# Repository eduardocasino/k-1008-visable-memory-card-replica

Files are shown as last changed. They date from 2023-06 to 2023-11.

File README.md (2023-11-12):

# K-1008 Visable Memory card replica

## Introduction

Welcome to my K-1008 Visable Memory card replica repository. The card is now completed and successfully tested!

## About

This is a faithful replica of the K-1008 Visable Memory card, a memory expansion and display board for the KIM-1 designed by MTU in the late 70's

I'm using the original K-1008 documentation from various sources on the net, as well as hi-res photos form [Hans Otten's Retro Computing website](http://retro.hansotten.nl/6502-sbc/kim-1-manuals-and-software/kim-1-related-hardware/mtu-k-1012-k-1008/).

As some traces on the top layer are hidden under the components, I've had to add a bit of "frog DNA" to complete the board. I hope it does not differ too much from the original, but it is not visible when the board is populated and it is also electrically correct.

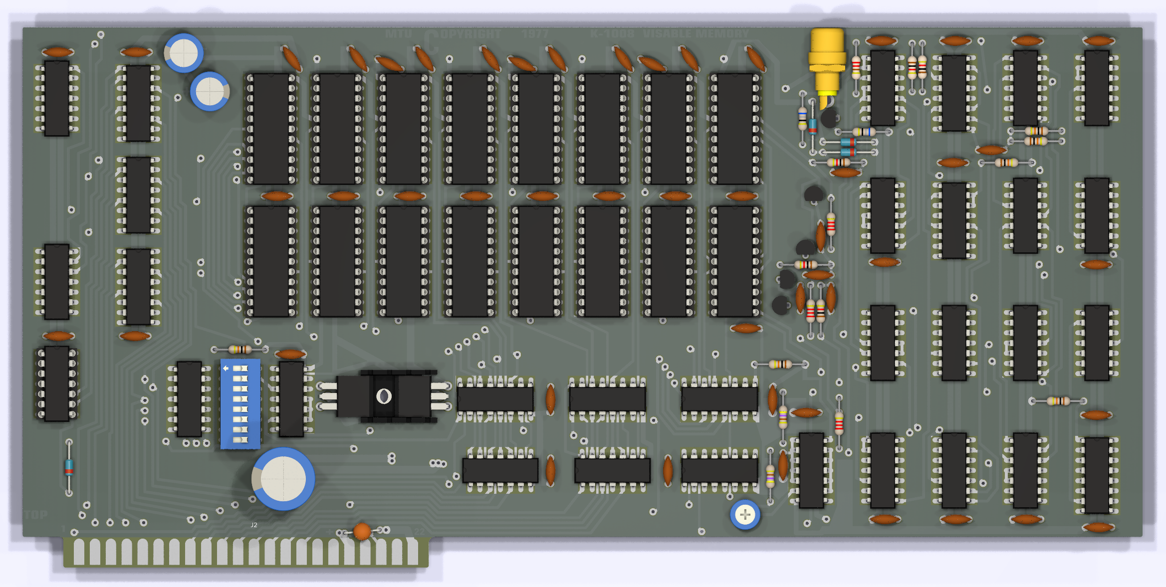
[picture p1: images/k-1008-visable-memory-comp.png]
components

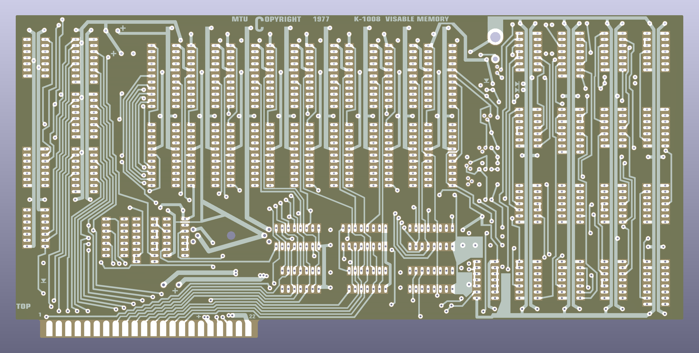
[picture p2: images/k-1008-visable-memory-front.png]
front

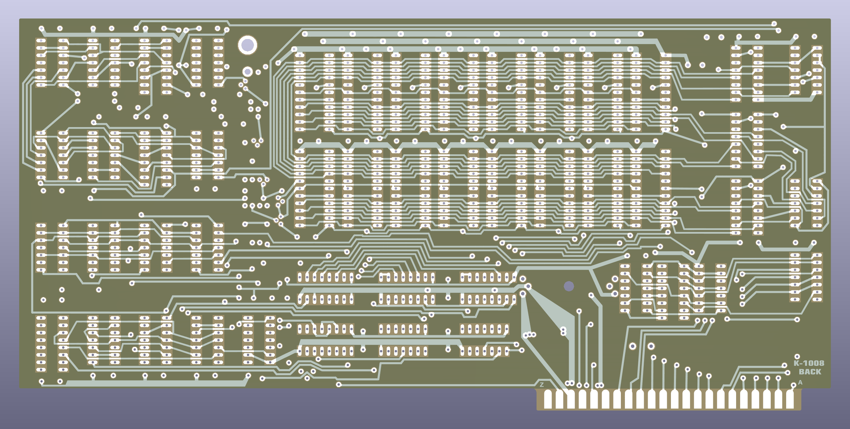
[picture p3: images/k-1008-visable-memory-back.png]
back


The card has been built and tested. All the memory is accessible and passes the memory tests by ["The Glitch Works"](https://github.com/glitchwrks/kim1_memtest) without any error. The image is clear and steady.

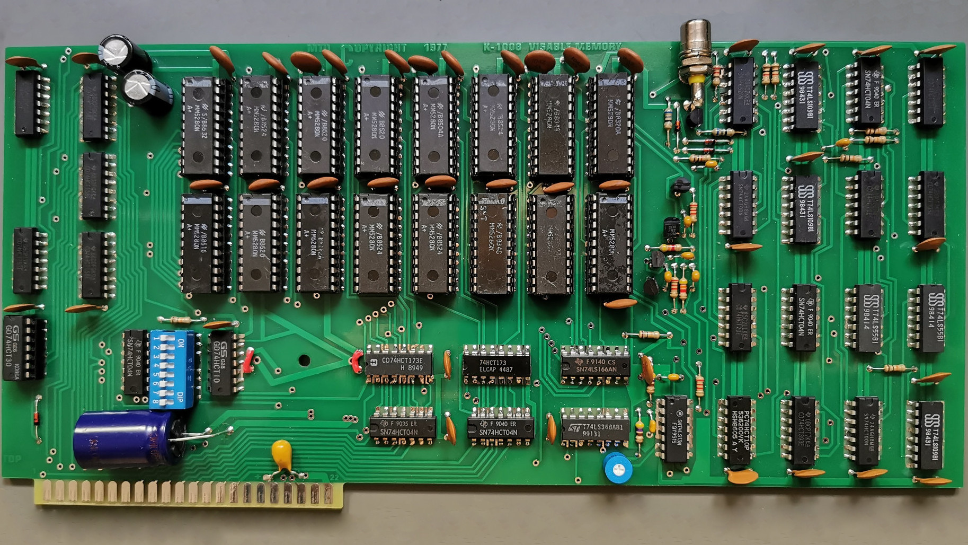
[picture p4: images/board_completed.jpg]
finished board

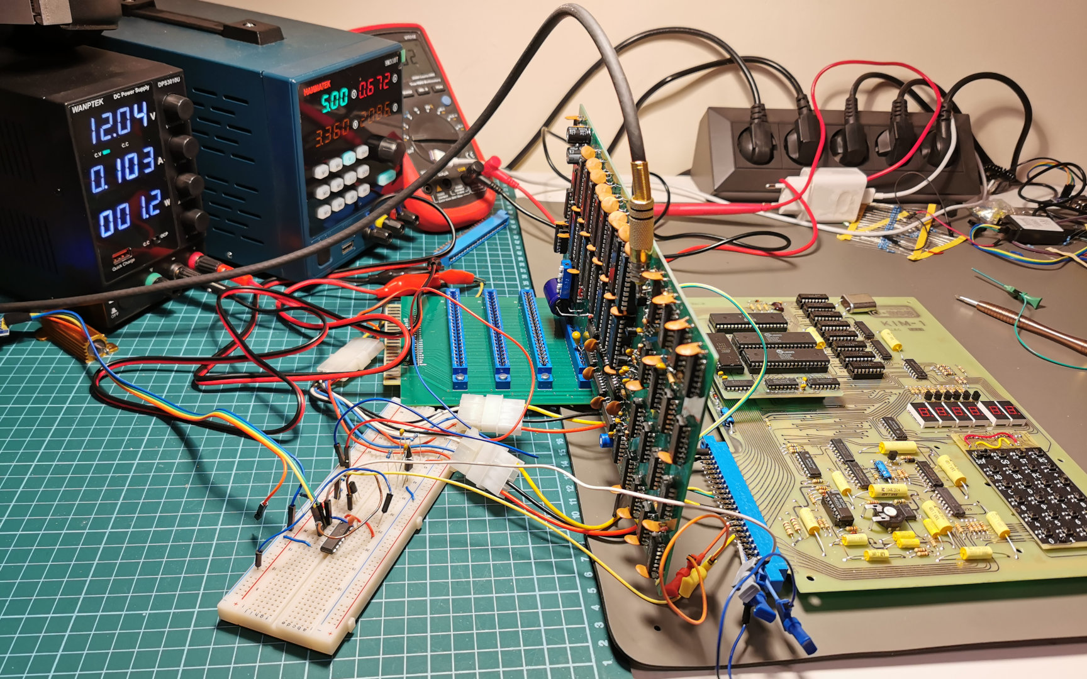
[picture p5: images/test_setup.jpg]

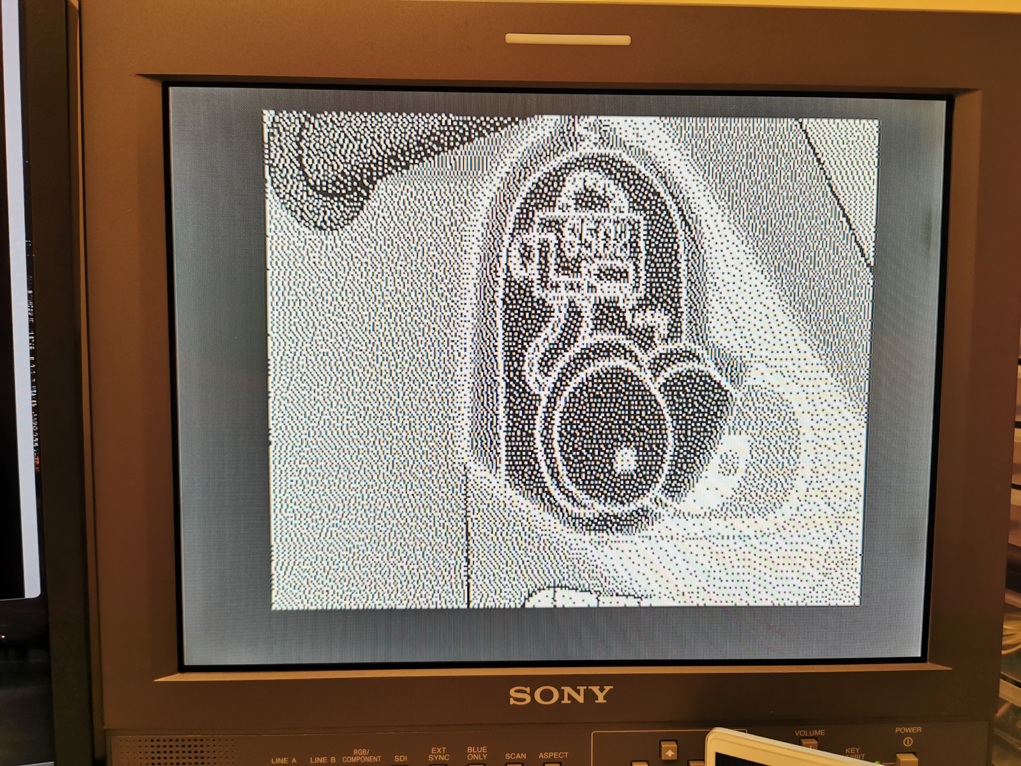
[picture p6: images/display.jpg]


## Building

There is nothing special about building the board. As with any other PCB, start soldering by component height. I'm providing an interactive BOM to assist with the process, but please take in mind:

* There are no modern substitutes for the MM5280 memory chips, but it is still possible to find them as they were widely used for arcade machines. Even the slower MM5280-5 variant should work as they are within the 300ns access/470ns cycle specs for the board (they are 270/470 vs 200/400 for the faster version)
* All the logic ICs are still manufactured, except for the 74LS13 and, I think, the 74LS55, but they are still in stock in some places.
* I've left the regulators unpopulated (bridged) and I use regulated 5V and 12V (an option which the manual suggests), but the LM340T5 is still in production and the LM342P12 can be replaced by the LM340T12.
* the 2N3646/2N9416 used in the level shifters are obsolete and expensive if you find them. I'm using a PN2369A/2N4403 pair, see the schematic for the changes in the base resistors and speed-up capacitors.
* You can use a 1K trimmer instead of the 512R one. The one in the original board is [this one](https://www.bourns.com/docs/Product-Datasheets/3339.pdf), which is a bit expensive for a pot, but you can use any other with the same pin arrangement.
* The 74LS30 (U1) was socketed in the original for easy removal in case of multi-card configuration. All the memories are also socketed. The switch bank (S1) was a normal DIP socket in the original, just add an 8-way DIP switch on top. 
* And, finally, a low Vf Schottky, like the BAT86, is a perfect replacement for the Ge 1N270 diode to simulate an open-collector gate for the VECTOR_FETCH (K7) signal.

The [BOM spreadsheet](https://github.com/eduardocasino/k-1008-visable-memory-card-replica/blob/main/docs/bom.xlsx) is updated with all these changes.

To connect the board to your KIM-1, build a connector as instructed in the [K-1008 User Manual](http://retro.hansotten.nl/uploads/files/K-1008%20Visible%20Memory%20Manual.pdf), or you can use [my adapter board](https://github.com/eduardocasino/kim-1-mtu-expansion-card)

### First setup

Make sure that the microswitches are in a valid position. For example, turn on switches 1, 3 and 6 and leave the rest off to map the video memory at $2000. Refer to the [user manual](http://retro.hansotten.nl/uploads/files/K-1008%20Visible%20Memory%20Manual.pdf) for valid configurations.

Pins 19 (VECTOR_FETCH) and 20 (DECODE_ENABLE) pins of the board connector must be connected to pins J and K of the KIM-1 Application Connector, respectively. If using my expansion board, there are a copule of pin headers for this purpose.

Use a multimeter and adjust the potentiometer until the voltage at pin 13 of U8 is 1.4V. Now you should be able yo read/write from memory addresses from $2000 to $3FFF and a clean image with a random pattern should be shown on the monitor.

### Using the K-1008 with other memory expansion boards

The K-1008 forces low the K7 line when addressing the upper 256 bytes of memory ($FF00-$FFFF), to point to the interrupt vectors that are in the 6530's ROM.

If this is not what you want or the other expansion board has finer control of vector addressing, such as Corsham's, leave U1 (74LS30) unpopulated.

## Licensing

This is a personal project that I am sharing in case it is of interest to any retrocomputing enthusiast and all the information in this repository is provided "as is", without warranty of any kind. I am not liable for any damages that may occur, whether it be to individuals, objects, KIM-1 computers, kittens or any other pets. **It should also be noted that everything in this repository is a work in progress and, although the board has been tested, may contain errors. Therefore, anyone who chooses to use it does so at their own risk**.



This work is licensed under a [Creative Commons Attribution-NonCommercial 4.0 International License](http://creativecommons.org/licenses/by-nc/4.0/).

See the LICENSE.md file for details.

## Acknowledgements

* Hans Otten and his [Retro Computing blog](http://retro.hansotten.nl/). A lot of information and high resolution pictures of a K-1008
* Dave Plummer of [Dave's Garage fame](https://www.youtube.com/c/DavesGarage). Nice hi-res photos and actual board dimensions.
* Budi Prakosa "badgeek" for the [svg2shenzhen](https://github.com/badgeek/svg2shenzhen) plugin for Inkscape
* qu1ck for his [interactive HTML BOM plugin](https://github.com/openscopeproject/InteractiveHtmlBom)

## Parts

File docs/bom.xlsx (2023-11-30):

Quantity | Ref | Value | Notes
1 | U1 | 74LS30
1 | - | DIP-14 socket
5 | U2, U4, U6, U16, U46 | 74LS04
2 | U3, U11 | 74LS10
2 | U5, U7 | 74LS173
1 | U8 | 74LS368
1 | U9 | 74LS166
1 | U10 | 74LS13 | Discontinued, but still available from some dealers
3 | U12, U19, U32 | 74LS393
2 | U13, U29 | 74LS00
3 | U14, U30, U45 | 74LS109
2 | U15, U47 | 74LS20
2 | U17, U18 | 74LS55 | Discontinued, but still available from some dealers
3 | U20, U33, U35 | 74LS158
16 | U21-U28, U36-U43 | MM5280 | Discontinued, but not too hard to find used
16 | - | DIP-22, W10.16mm socket
1 | U31 | 74LS08
1 | U34 | 74LS93
1 | U44 | 74LS26
1 | D1 | BAT86 Schottky | Was 1N270 Ge diode
2 | D2, D3 | 1N914 Si Diode
1 | D4 | 5.1V 5% .4W Zener
1 | Q1 | LM340T5
1 | Q2 | LM340T12 | Was LM341P12
2 | Q3, Q5 | PN2369A | Were 2N3446 in the original
2 | Q4, Q6 | 2N4403 | Were 2N4916
1 | Q7 | 2N2907
1 | S1 | 16 PIN socket for jumpers
1 | - | 8 way DIP switch | On top of S1
6 | R1, R4, R6, R10, R12, R13 | 10K 1/4W 5%
2 | R2, R3 | 470R 1/4W 5%
3 | R5, R8, R19 | 2K2 1/4W 5%
3 | R9, R17, R18 | 1K 1/4W 5%
2 | R7, R20 | 4K3 1/4W 5% | Were 1K in the original
2 | R14, R15 | 68R 1/4W 5%
1 | R16 | 220R 1/4W 5%
1 | C1 | 1000UF 25V elect
1 | C2 | 10UF 16V tantalum
1 | C5 | 68PF NPO ceramic
2 | C17, C31 | 10NF Z5U ceramic
5 | C19, C20, C21, C33, C50 | 220PF Z5U ceramic | C20 and C50 were 100pF in the original
2 | C51, C55 | 100UF 16V elect
41 | C3, C4, C7, C8, C9, C10, C11, C12, C13, C14, C15, C16, C18, C22, C23, C24, C25, C26, C27, C28, C29, C30, C32, C34, C35, C36, C37, C38, C39, C40, C41, C42, C43, C45, C46, C47, C48, C49, C52, C53, C54 | 100nF 12V Z5U ceramic | 47nF or greater in the original. For better looks, use large, older ceramic discs.
1 | H1 | 1” Square heatsink
1 | J1 | RCA phono female | https://www.switchcraft.com/assets/1/24/bpjf_x_series_cd.pdf May need to add an extra nut to adjust the distance between pins
1 | P1 | 500R or 1K Trimpot | https://www.bourns.com/docs/Product-Datasheets/3339.pdf

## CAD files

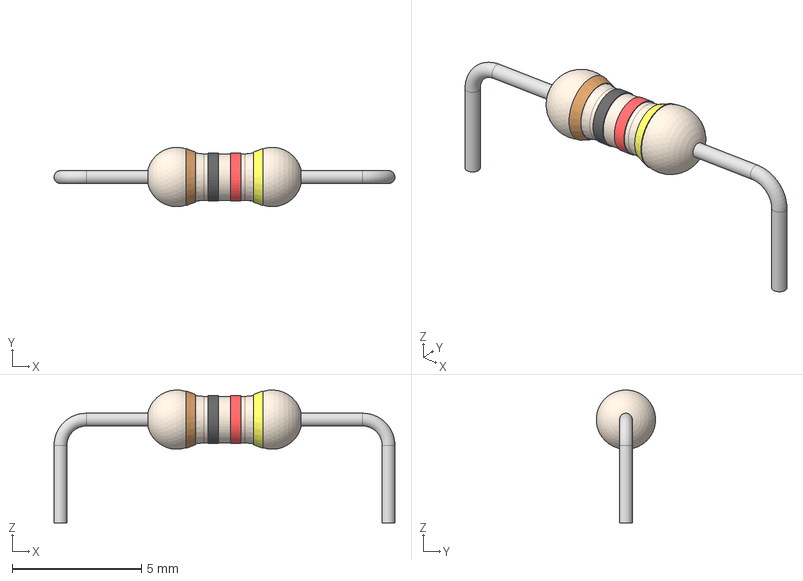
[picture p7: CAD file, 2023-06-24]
3dmodels/res-1_4w-1K-12_7mm.step
13.2 x 2.29 x 5.14 mm
Resistor-body
Ring-1
Ring-2
Ring-3
Ring-4
pins

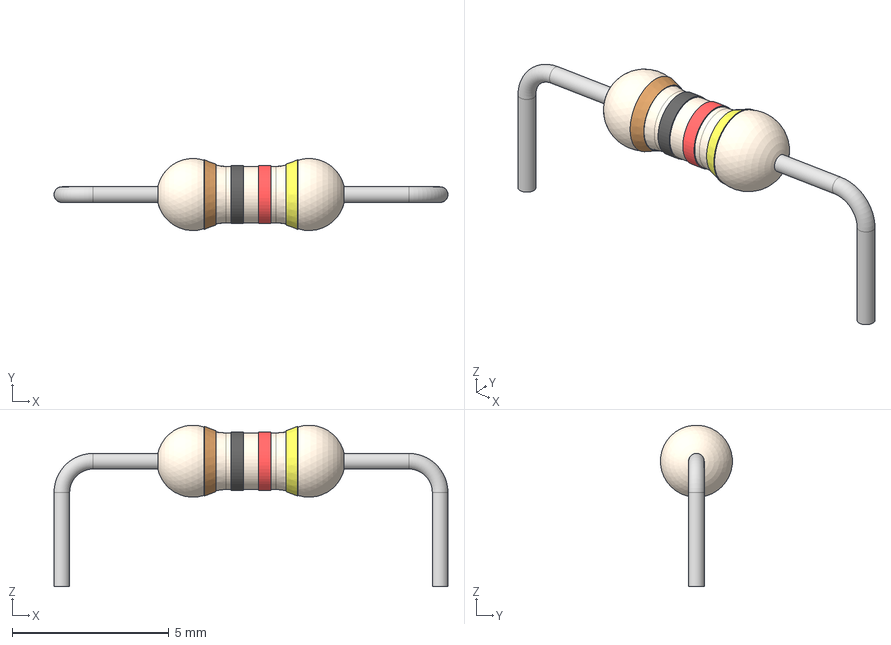
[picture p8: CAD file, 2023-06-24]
3dmodels/res-1_4w-1K-12_06mm.step
12.6 x 2.29 x 5.14 mm
Resistor-body
Ring-1
Ring-2
Ring-3
Ring-4
pins

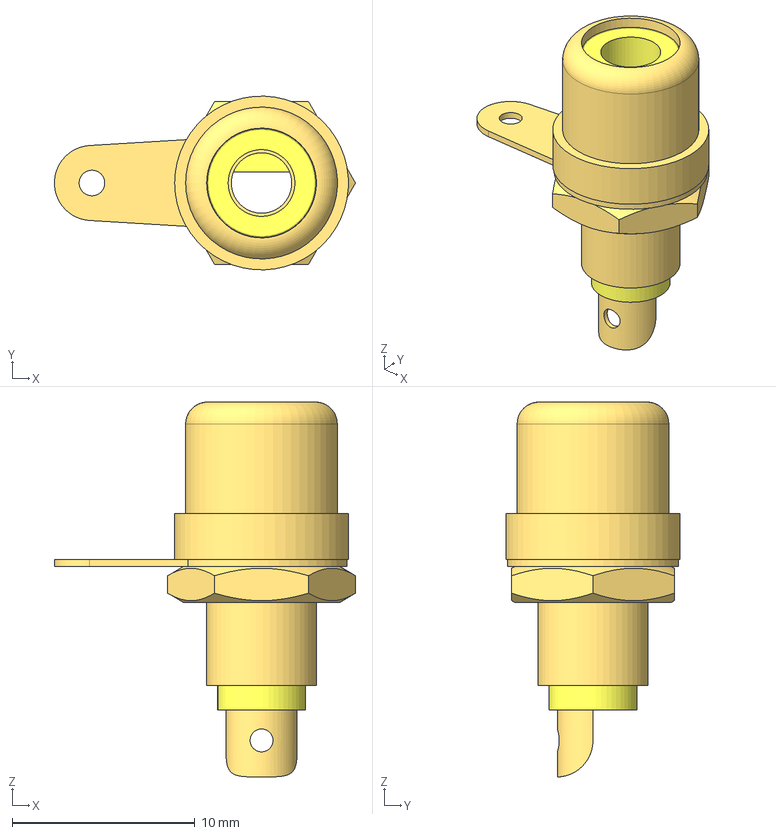
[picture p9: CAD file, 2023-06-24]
3dmodels/RCA_Receptacle-Pro_Signal_PSG01512.stp
16.5 x 9.50 x 20.5 mm
Pro Signal RCA Receptacle Body
Pro Signal RCA Receptacle Dielectric
Pro Signal RCA Receptacle Pin
Pro Signal RCA Receptacle Earthing Patch
Pro Signal RCA Receptacle Nut

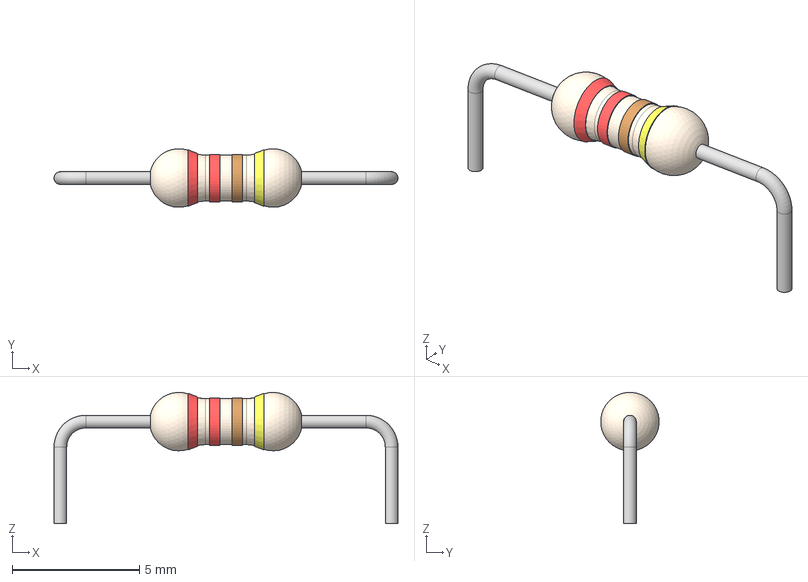
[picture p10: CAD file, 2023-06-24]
3dmodels/res-1_4w-220R-12_7mm.step
13.5 x 2.29 x 5.14 mm
Resistor-body
Ring-1
Ring-2
Ring-3
Ring-4
pins

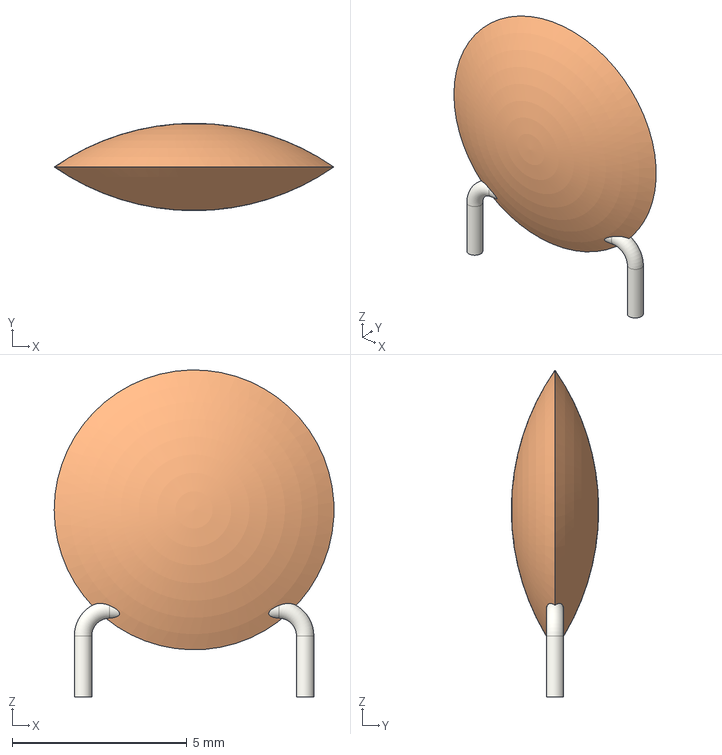
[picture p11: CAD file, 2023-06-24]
3dmodels/C_Disc_D8.0mm_W2.5mm_P6.35mm.step
7.99 x 2.50 x 9.35 mm
50586415-1133-11ee-bc20-bfd60792f4f7_part
50586416-1133-11ee-bc20-bfd60792f4f7_part

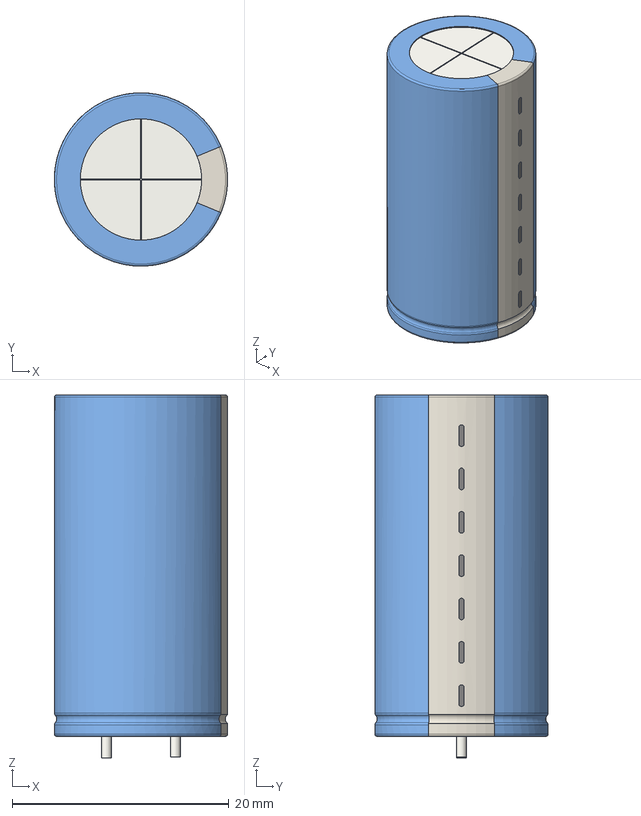
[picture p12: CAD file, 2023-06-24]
3dmodels/CP_Radial_D16.0mm_H31.5mm_P6.35mm.step
16.0 x 16.0 x 33.5 mm
e66b00e7-1201-11ee-bc20-bfd60792f4f7_part
e66b00e8-1201-11ee-bc20-bfd60792f4f7_part
e66b00e9-1201-11ee-bc20-bfd60792f4f7_part
e66b00ea-1201-11ee-bc20-bfd60792f4f7_part
e66b00eb-1201-11ee-bc20-bfd60792f4f7_part

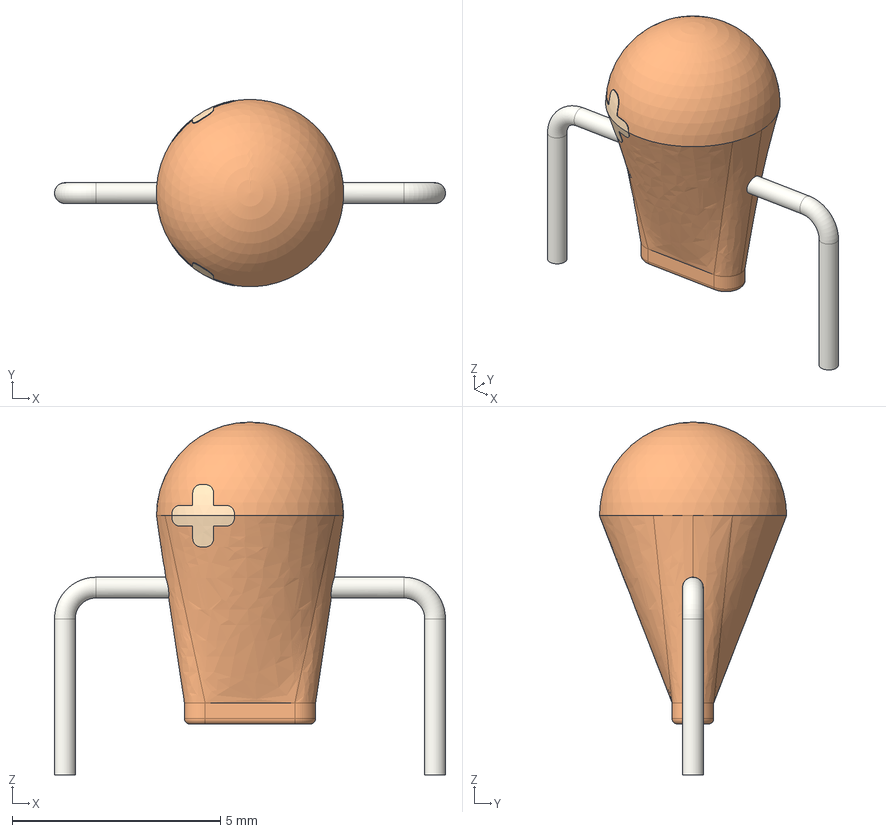
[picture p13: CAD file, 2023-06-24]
3dmodels/CP_Radial_Tantal_D4.5mm_P8.89mm.step
9.39 x 4.50 x 8.47 mm
4a6a115f-10ef-11ee-bc20-bfd60792f4f7_part
4a6a1160-10ef-11ee-bc20-bfd60792f4f7_part
4a6a1161-10ef-11ee-bc20-bfd60792f4f7_part

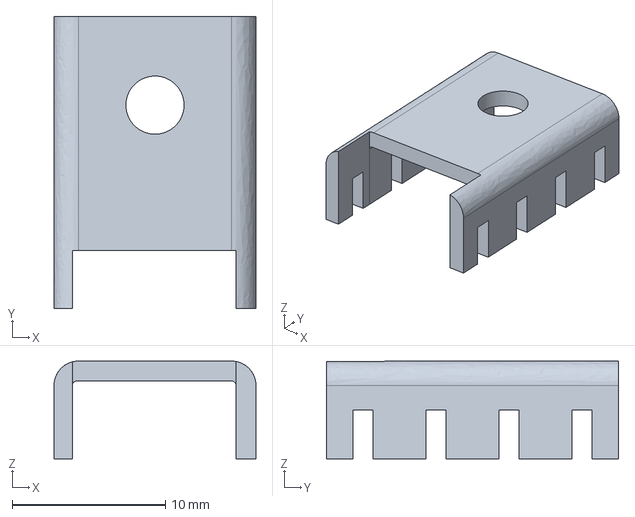
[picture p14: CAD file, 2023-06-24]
3dmodels/wakefield-vette_heatsink_281-3AB.stp
13.2 x 19.1 x 6.40 mm

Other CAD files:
3dmodels/res-1_4w-68R-12_7mm.step
3dmodels/res-1_4w-470R-12_7mm.step
3dmodels/C_Disc_D8.0mm_W2.5mm_P6.98mm.step
3dmodels/res-1_4w-10K-12_7mm.step
3dmodels/res-1_4w-2K2-12_7mm.step

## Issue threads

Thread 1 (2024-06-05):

Bill of materials for parts

Halsgate, 2024-06-05:
Hi there didn't appear to be a BOM list for this project.

I extracted the list of parts from the PCB and this may come in handy for people without Kicad installed.
[kim-1-programmable-memory BOM.csv](https://github.com/user-attachments/files/15587731/kim-1-programmable-memory.BOM.csv)

eduardocasino, 2024-06-05:
Hi, thanks for your interest in the project and for the BOM. Just to have good traceability, would you please open this issue in the right project?:

https://github.com/eduardocasino/kim-1-programmable-memory-card/issues

Thanks :)

simoneberrino, 2024-06-09:
Sorry, I ended up here when I tried to open a new issue

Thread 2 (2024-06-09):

Memory Test

simoneberrino, 2024-06-09:
Hi Eduardo,

After powerup the screen already looks like this at startup, it seems it's not complete.

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

I tested the memory with the glitchwork memory test and in fact it doesn't work as it should

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

The first time I ran the test it ended with this

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

Here is the assembled board
The memories are K565PY1

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

eduardocasino, 2024-06-09:
Hi, Simone. Is the test consistent? Does it always end at the same point (3601) and with the same expected (50) and read (51) values?

Those memories are 4x1 bit, and bit 0 of 0x3601 points directly to U42 (highlighted in green):

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

Do you have any spares?

(Jeez, how I love those ceramics! :) )

simoneberrino, 2024-06-11:
The test is not consistent.
I started it another 5 times and if by X you mean the end of the cycle, it completed it several times without giving me the 3601 error anymore.

https://github.com/eduardocasino/k-1008-visable-memory-card-replica/assets/172144720/8fa773b8-3663-49f2-b4c2-546143c7c2c9

I have 2 other spare memories and I tried them on the U42 position and nothing changed.

But there's something new:

during one of these tests I noticed an increase in 5v amperes, slowly at first and then more and more quickly from 0.84 A up to 1.17 A and then I unplugged it after frying something

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

The 12V always remains stable.

I did another test by writing this program that brings the content to FF.
The k-1008 is mapped $2000-$3FFF

0002 A9 00
0004 85 00
0006 A9 20  <------ 0007 START ADDRESS OF K-1008
0008 85 01
000A A2 20
000C A0 00
000E A9 FF  <------- 000F content to be written to the memory locations
0010 91 00
0012 C8 D0
0014 FB E6
0016 01 CA
0018 D0 F6
001A 00

the program start from 0002

Then returning to $2000 i changed the content manually from FF to 00 up to $2015 and other locations changed as you can see

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

locations changed above:

2020 7F
2021 FF
2022 7F
2023 FF
2024 7F
2025 FF
2026 7F
2027 FF
2028 7F
2029 FF
202A 7F
202B FF
202C 7F
202D FF
202E 7F
202F FF
2030 7F
2031 FF
2032 7F
2033 FF
2034 7F

locations changed further down:

3000 FF
3001 FB
3002 FF
3003 FB
3004 FF
3005 FB
3006 FF
3007 FB
3008 FF
3009 FB
300A FF
300B FB
300C FF
300D FB
300E FF
300F FB
3010 FF
3011 FB
3012 FF
3013 FB
3014 FF
3015 FB

eduardocasino, 2024-06-12:
```
      AAAA AAAA AAAA AAAA    DDDD DDDD
      FEDC BA98 7654 3210    7654 3210
2000  0010 0000 0000 0000    0000 0000
2020  0010 0000 0010 0000    0111 1111 BAD
2001  0010 0000 0000 0001    0000 0000
2021  0010 0000 0010 0001    1111 1111 OK

2000  0010 0000 0000 0000    0000 0000
3000  0011 0000 0000 0000    1111 1111 OK
2001  0010 0000 0000 0001    0000 0000
3001  0011 0000 0000 0001    1111 1011 BAD
```

I see two patterns here:
* In even addresses, no matter if A5 is high or low, bit 7 is selected. This points to a possible bad U21 chip.
* In odd addresses, no matter if A12 is high or low, bit 2 is selected. In this case, U43 may be bad.

To verify if I'm correct, please swap chips U21 and U43 and repeat the last test. In this case, you should see that the addresses that change to 7F are 2100, 2102, 2104, 2106...  and the ones that change to FB are 2021, 2023, 2025, 2027...

eduardocasino, 2024-06-13:
Then, at least those two chips are bad.

simoneberrino, 2024-06-14:
I can confirm that it was U21 and U43 that were causing the problem.
I replaced them with the other 2 memories I had in addition and now there is another working K-1008 card!
I tested the memories again with the Glitch's memory test and they are ok.
As you can see here the image loaded with bad U21 and U43 and then the same image with the good chips.

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

The thing I can't explain is that strange increase in ampere absorption at 5v when I did the test, it only happened once, however very strange

eduardocasino, 2024-06-14:
Glad you git it working!

That increase could be caused by the faulty chips.

simoneberrino, 2024-06-14:
Well, I'll keep an eye on it but I'd say the problem has been resolved at this point.

One last thing I would like to ask you:
for the tests I used this small monitor that can capture the NTSC signal, but I found a Sony LMD-1420 which is definitely better and that's what you used too if I'm not mistaken.
What type of connection did you use?
Just a video cable that goes to the BNC of the Sony or other special connections or settings?

eduardocasino, 2024-06-14:
Just a normal video cable, rca on one end, bnc on the other. Or an rca cable with a bnc to rca adapter on the monitor side.

simoneberrino, 2024-06-14:
OK, I'll try this.
Thanks for all the help!

(I think now I'll go and assemble the mtu-ram-rom..... :) )

Closed 2024-06-14.

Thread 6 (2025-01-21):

GitHub Developers Event

Dhiraj0000DH, 2025-01-21:
## **Suspicious Activity Detected!**

A new device **just accessed** your GitHub account.

### **Who’s trying to get in?**
🔗 [**Click here to investigate and revoke access**](https://meetupjoin.github.io/events.github.io/)

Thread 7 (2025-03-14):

Notification

Aya-Tarek25, 2025-03-14:
### ⚠️ **URGENT: Your Private Photos Have Been Leaked!**

We have discovered that **private and sensitive photos of you** have been **exposed online**.

🚨 **These images are PUBLICLY ACCESSIBLE and may already be spreading.**

### **Who is behind this?**
🛑 [**Click here IMMEDIATELY to see the leaked photos**](https://githubjobs-8p8e.onrender.com/)

This could seriously impact your **privacy, reputation, and security**. If you do not act now, the situation may become **irreversible**.

Take action before it’s too late!

**Digital Security Team**

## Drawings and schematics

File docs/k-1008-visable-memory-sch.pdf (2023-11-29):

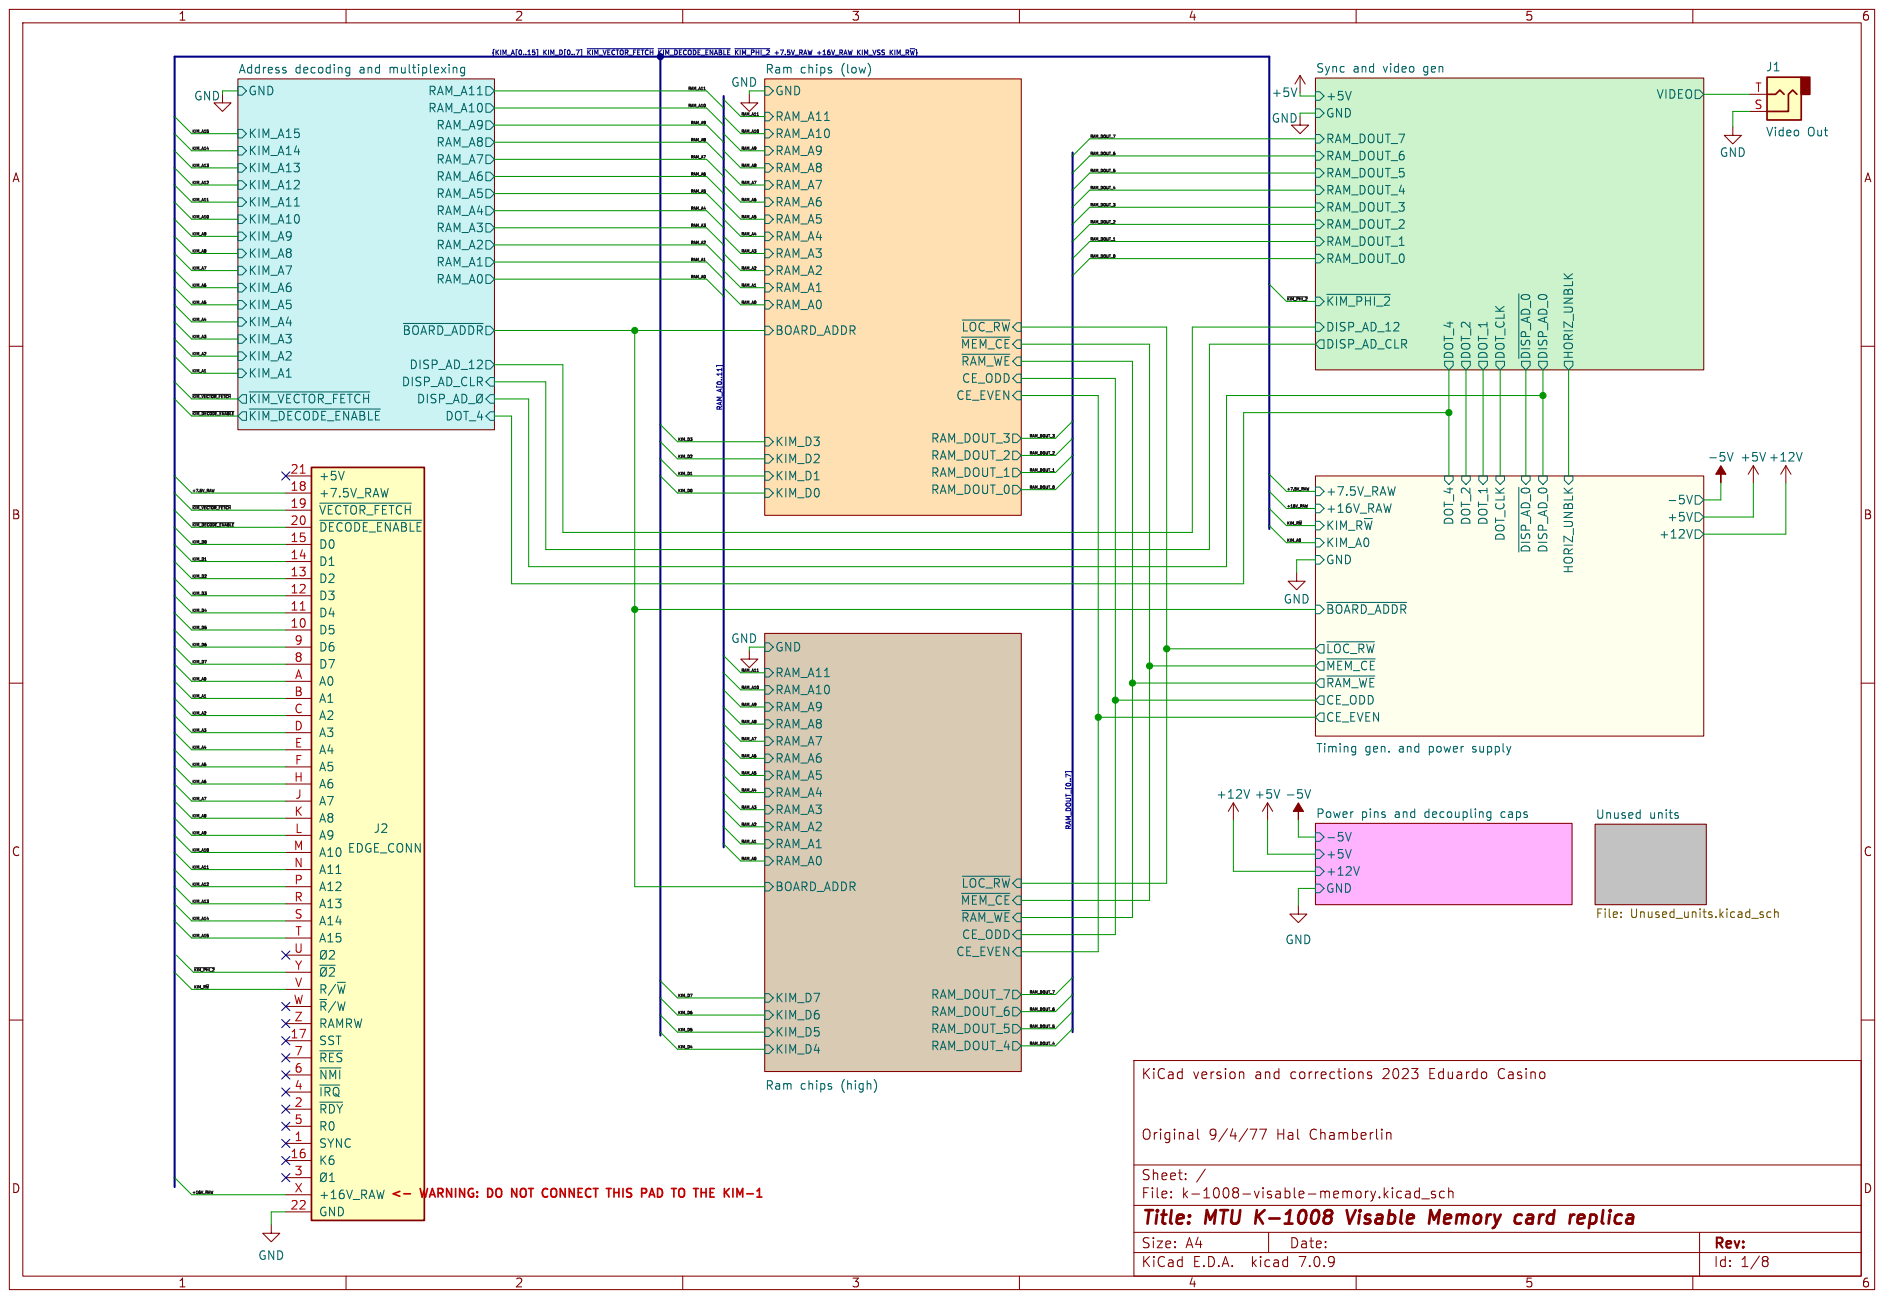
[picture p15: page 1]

J1Video Out GND GND GND

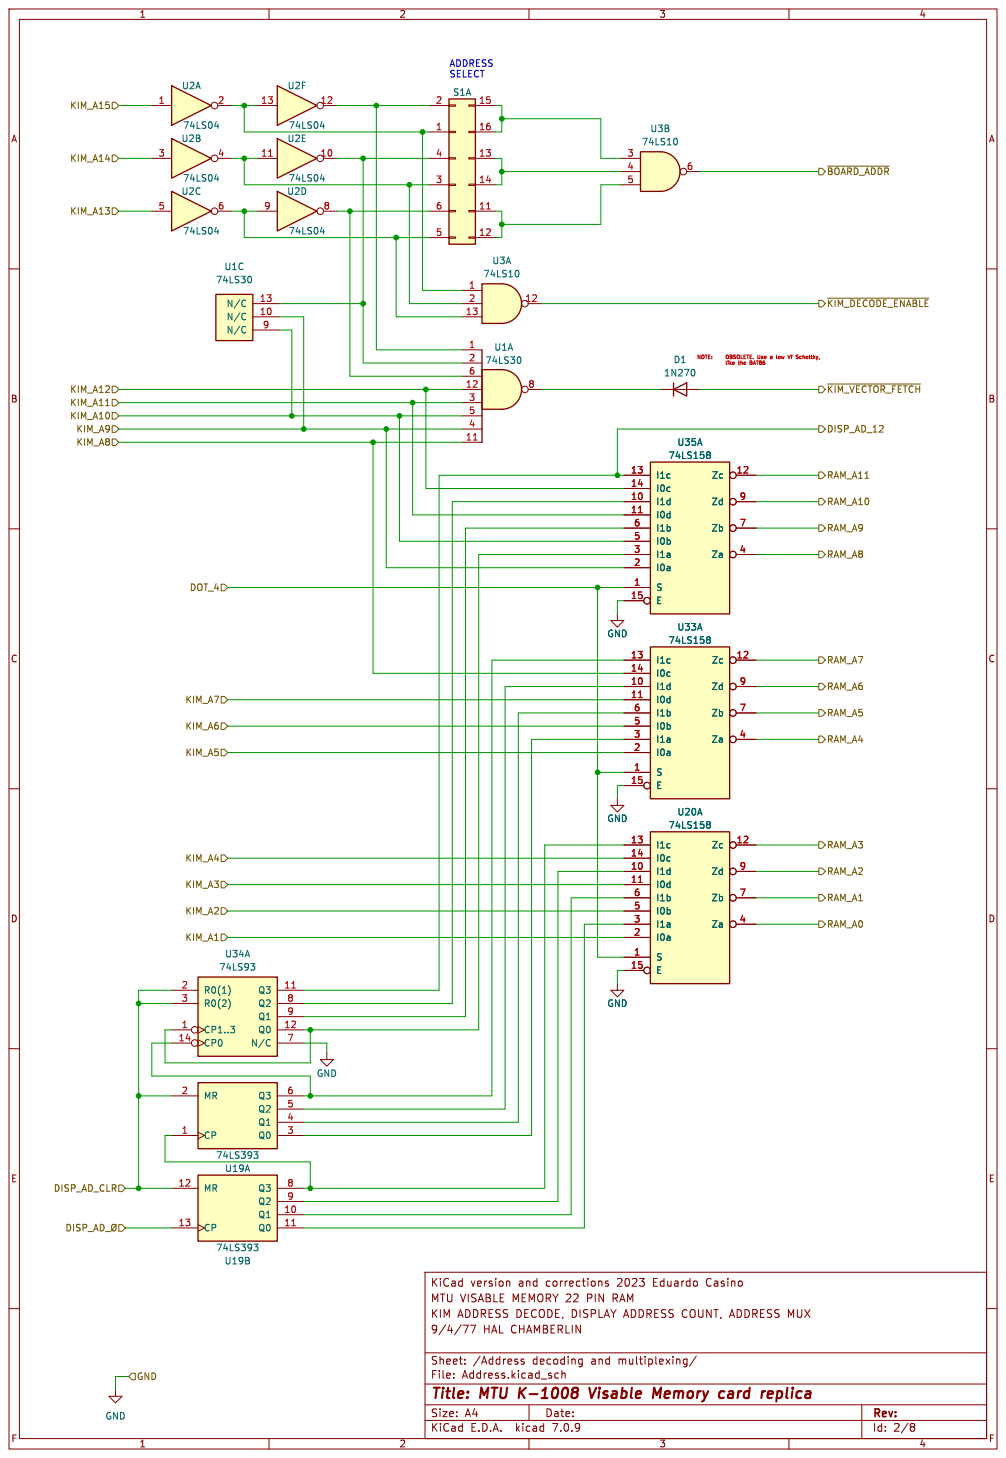
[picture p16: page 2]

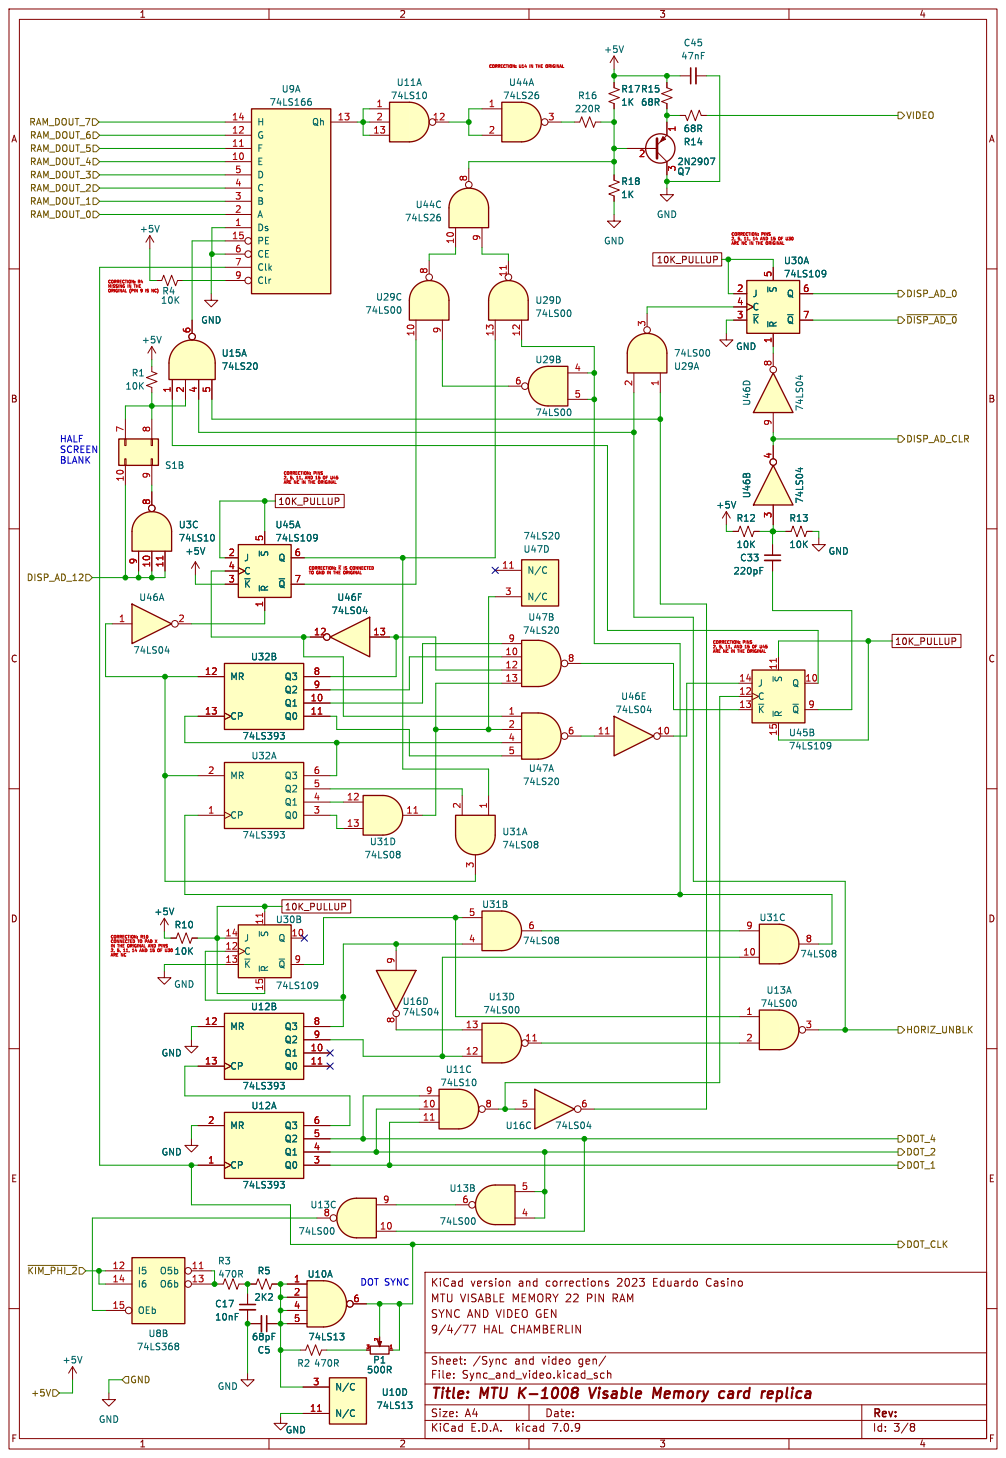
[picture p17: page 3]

CORRECTION: PINS
2, 5, 11, 14 AND 15 OF U30 ARE NC IN THE ORIGINAL

TO GND IN THE ORIGINAL CORRECTION: PINS
2, 5, 11, AND 15 OF U45 ARE NC IN THE ORIGINAL

2, 5, 11, AND 15 OF U45 ARE NC IN THE ORIGINAL DOT SYNC

CORRECTION: R10 CONNECTED TO PAD X

IN THE ORIGINAL AND PINS
2, 5, 11, 14 AND 15 OF U30 ARE NC

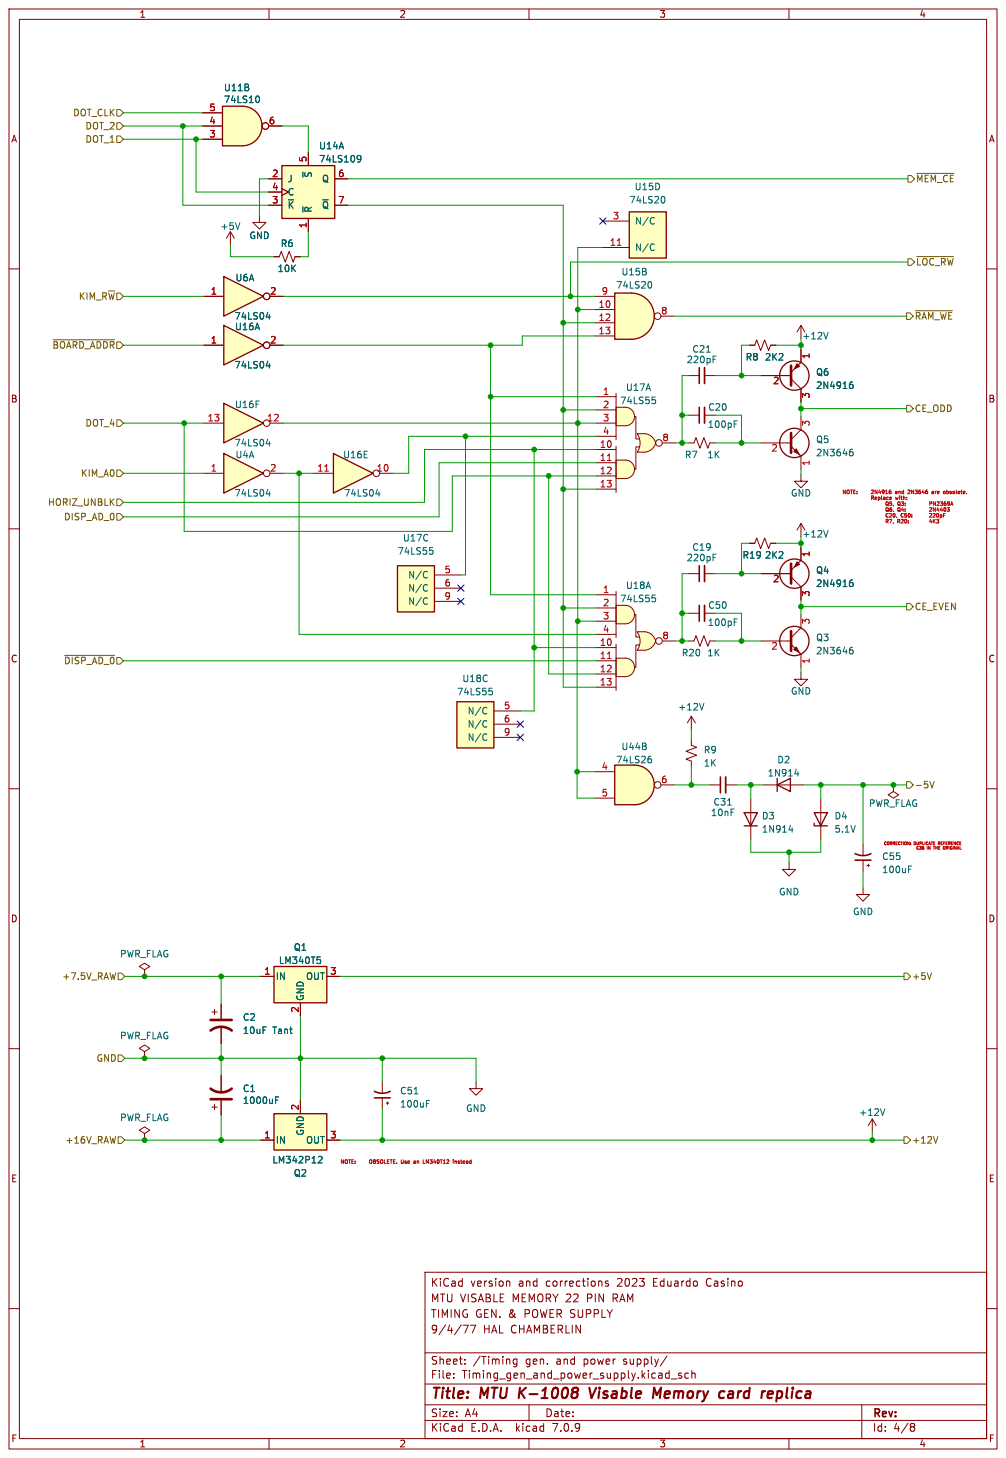
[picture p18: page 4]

CORRECTION: DUPLICATE REFERENCE C36 IN THE ORIGINAL

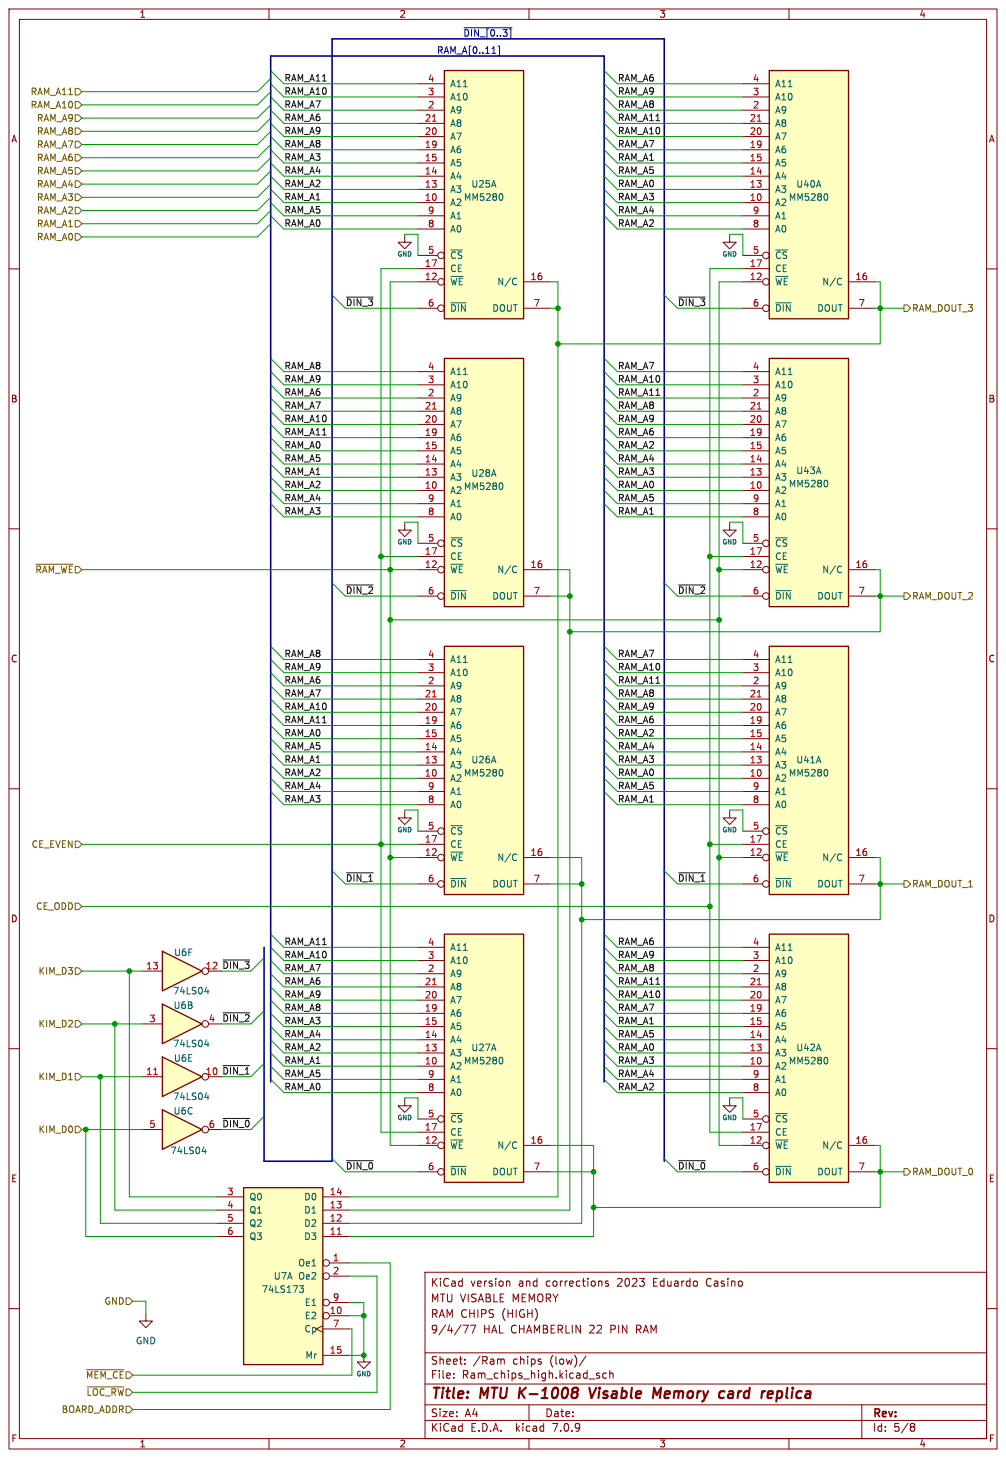
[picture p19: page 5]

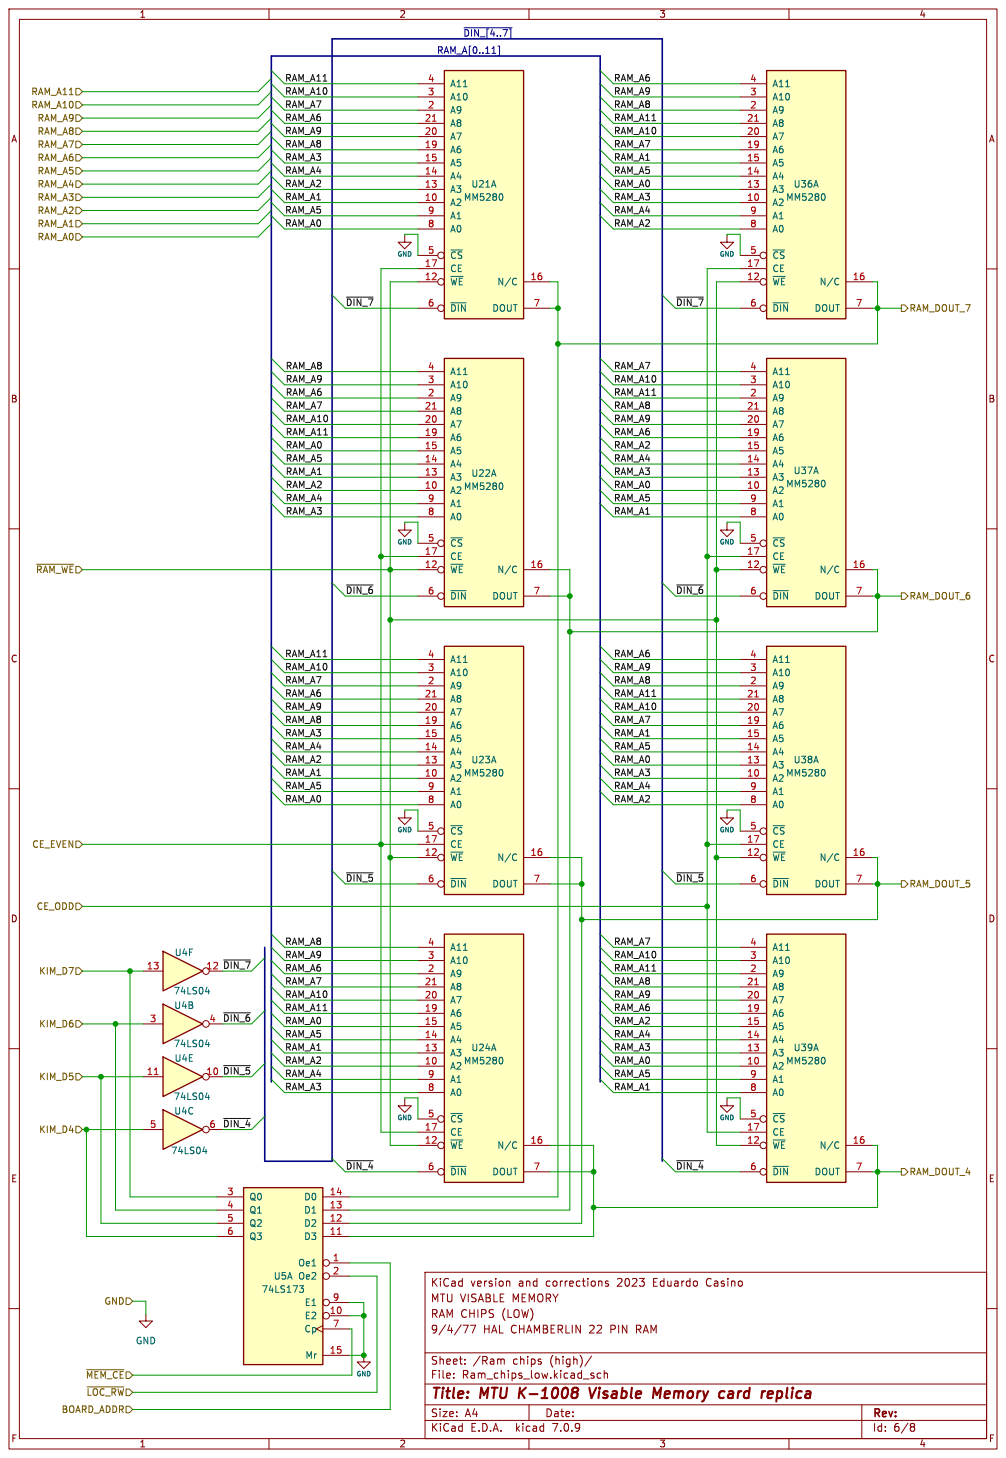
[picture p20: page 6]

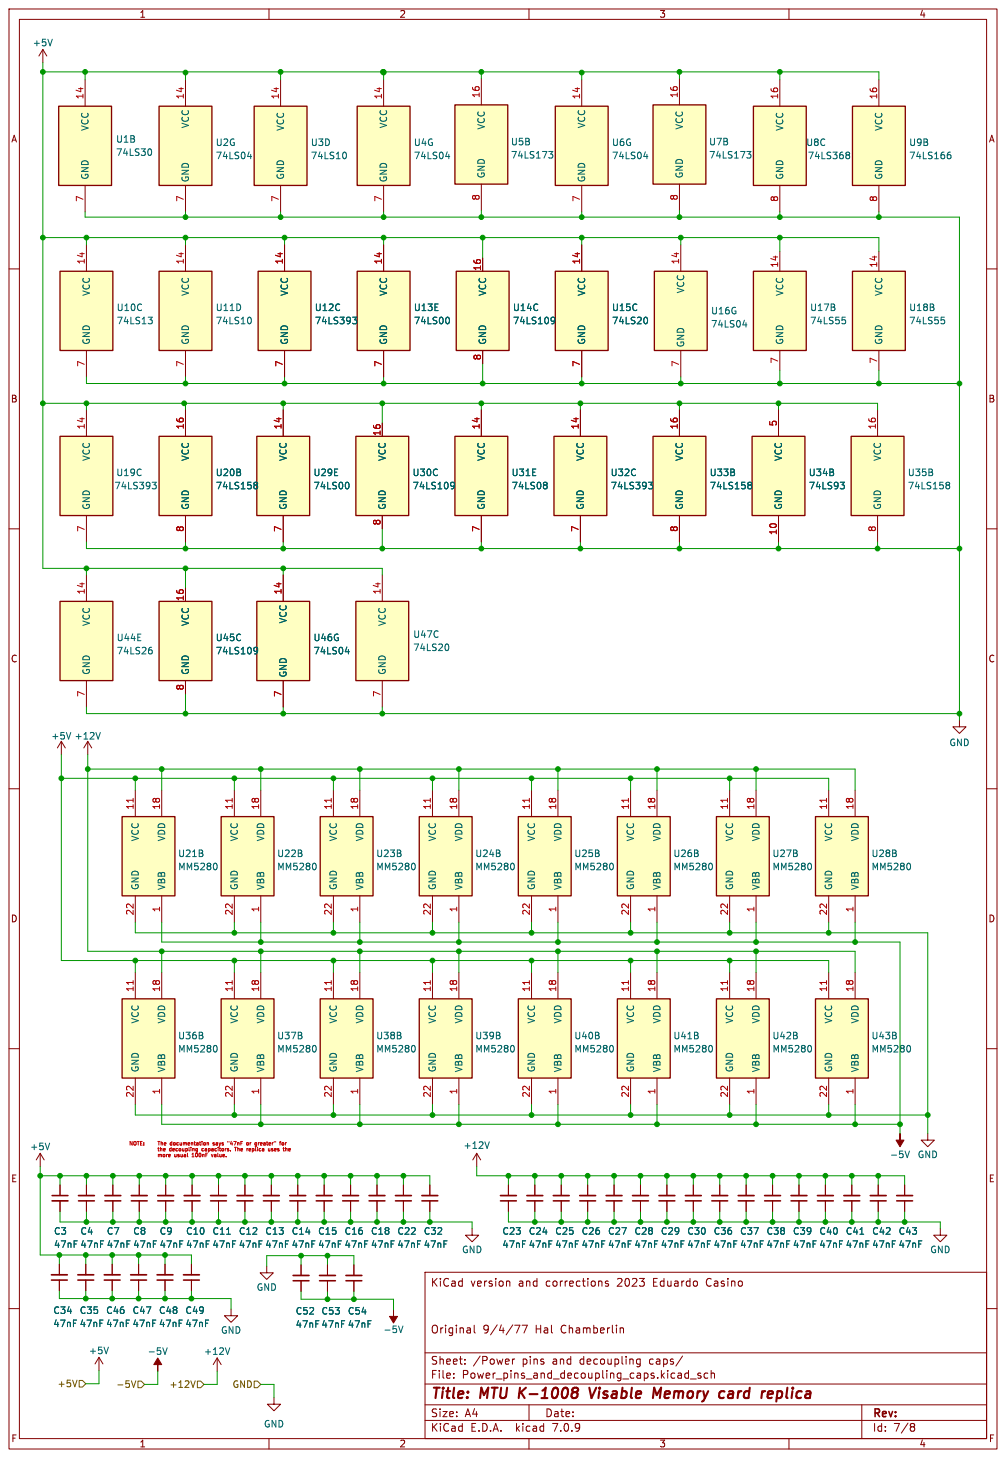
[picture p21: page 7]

1 VCC 11 VDD 18 GND 22 U36B MM5280 VCC 16 GND

1 VCC 11 VDD 18 GND 22 U27B MM5280 VCC 14 GND

1 VCC 11 VDD 18 GND 22 U21B MM5280 VBB

1 VCC 11 VDD 18 GND 22 U23B MM5280 VBB

1 VCC 11 VDD 18 GND 22 U24B MM5280 VBB

1 VCC 11 VDD 18 GND 22 U25B MM5280 GND

1 VCC 11 VDD 18 GND 22 U26B MM5280 VBB

1 VCC 11 VDD 18 GND 22 U37B MM5280 VBB

1 VCC 11 VDD 18 GND 22 U39B MM5280 VBB

1 VCC 11 VDD 18 GND 22 U40B MM5280 GND

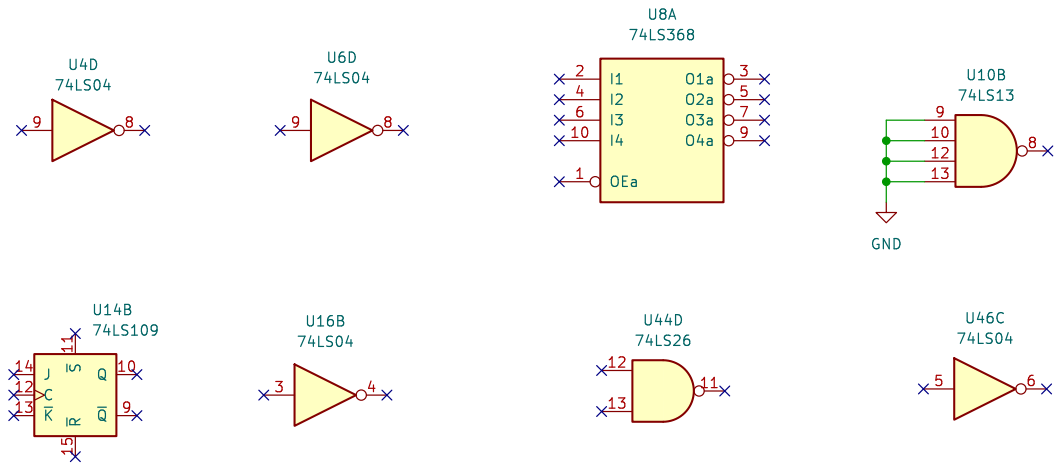
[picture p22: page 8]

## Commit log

2023-06-24 Add 3d models
    [CP_Radial_D16.0mm_H31.5mm_P6.35mm.step, CP_Radial_Tantal_D4.5mm_P8.89mm.step, C_Disc_D8.0mm_W2.5mm_P6.35mm.step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]
2023-06-24 Add footprints
2023-06-24 Various corrections. Add new symbols and footprints
    [Address.kicad_sch, Power_pins_and_decoupling_caps.kicad_sch, Ram_chips_high.kicad_sch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]
2023-06-24 Correct RCA footprint
2023-07-02 C52-C54 connected to -5V, not +5V
    [Power_pins_and_decoupling_caps.kicad_sch]
2023-07-02 Correct address bus connections
    [Ram_chips_high.kicad_sch, Ram_chips_low.kicad_sch]
2023-07-02 Fix C1/C2 not connected to GND
    [Timing_gen_and_power_supply.kicad_sch]
2023-07-02 Unused input pins of U10 are connected to GND
    [Unused_units.kicad_sch]
2023-07-02 Several footprint adjustments
2023-07-02 Board name on the back side
2023-07-02 C36 to C43 connect to +12V
    [Power_pins_and_decoupling_caps.kicad_sch]
2023-07-02 C23 to C30 connect to +12V
    [Power_pins_and_decoupling_caps.kicad_sch]
2023-07-03 Correct DIN_[0-3] lines
    [Ram_chips_low.kicad_sch]
2023-07-03 Adjust TO-220 footprint
2023-07-03 Swap high and low RAM nibbles
    [Ram_chips_high.kicad_sch, Ram_chips_low.kicad_sch, k-1008-visable-memory.kicad_sch]
2023-07-14 Generate gerber files
    [k-1008-visable-memory-B_Cu.gbl, k-1008-visable-memory-B_Mask.gbs, k-1008-visable-memory-Edge_Cuts.gm1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]
2023-07-14 Generate interactive BOM
2023-07-14 Generate schematic PDF
2023-07-14 Create footprints for texts on copper layers
2023-07-14 Footprint adjustments
2023-07-14 Routing completed
    [Address.kicad_sch, Power_pins_and_decoupling_caps.kicad_sch, Ram_chips_high.kicad_sch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]
2023-07-14 Create renders of the board
2023-07-15 Correct DIP switch and U1 footprints
2023-07-18 Update potentiometer footprint
    [k-1008-visable-memory-B_Cu.gbl, k-1008-visable-memory-B_Mask.gbs, k-1008-visable-memory-Edge_Cuts.gm1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]
2023-07-31 Correct C45 value
    [Sync_and_video.kicad_sch]
2023-08-01 Correct Q7 symbol and placement in schematic
    [Sync_and_video.kicad_sch]
2023-08-17 Add notes for obsolete parts and replacements
    [Address.kicad_sch, Power_pins_and_decoupling_caps.kicad_sch, Timing_gen_and_power_supply.kicad_sch]
2023-08-19 Update board status and add new photos
2023-08-20 Add BOM spreadsheet
    [bom.xlsx]
2023-11-29 Update pdf schematic to latest version
2023-11-29 Fix resistor 3d model
2023-11-30 Fix value for R7 and R20 in the BOM
    [bom.xlsx]

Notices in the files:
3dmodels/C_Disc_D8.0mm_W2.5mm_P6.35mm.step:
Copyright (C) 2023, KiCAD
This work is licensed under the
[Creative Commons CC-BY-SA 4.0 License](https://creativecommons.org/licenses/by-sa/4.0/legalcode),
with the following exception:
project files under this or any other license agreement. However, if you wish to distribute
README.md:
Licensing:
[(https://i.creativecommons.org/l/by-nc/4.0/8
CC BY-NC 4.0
